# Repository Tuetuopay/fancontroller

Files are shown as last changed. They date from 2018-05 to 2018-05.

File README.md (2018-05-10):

# FanController

*Creative naming?* What is this?

Rheobus project rooted from a simple problem: all my PC fans are DC only (the
three wire kind), but my motherboard only supports PWM*. And why buy a
commercial one? Let's make my own!

*Even if it does, shhhh! This is a good excuse for a project!

## Hardware

Simple PCB designed with Eagle. It can control up to 8 fans, with an STM32F103
as a brain. On the extra side, there is an LED for each channel, because
blinkenlights are cool. For communications, this is scarce: a USB port and
UART or I2C header.

The PCB is mostly finished, some refinements may be needed. It is well under
10cm x 10cm to be ordered on the cheap from the likes of DirtyPCB or JLCPCB.

All parts are SMD (except for headers and the one quartz), but do not go smaller
than 0603 resistors, easily solderable by hand. They can all be easily sourced
from Ebay.

## Software

This is not written yet. I plan on doing it with ChibiOS, just for kicks. It is
well supported on the STM32 platform, easy to use (once you accepted the fact
that documentation is almost nonexistent).

# Licence

```
THE BEER-WARE LICENSE (Revision 42):
tuetuopay at me dot com wrote this file. As long as you retain this notice you
can do whatever you want with this stuff. If we meet some day, and you think
this stuff is worth it, you can buy me a beer in return. Tuetuopay.
```

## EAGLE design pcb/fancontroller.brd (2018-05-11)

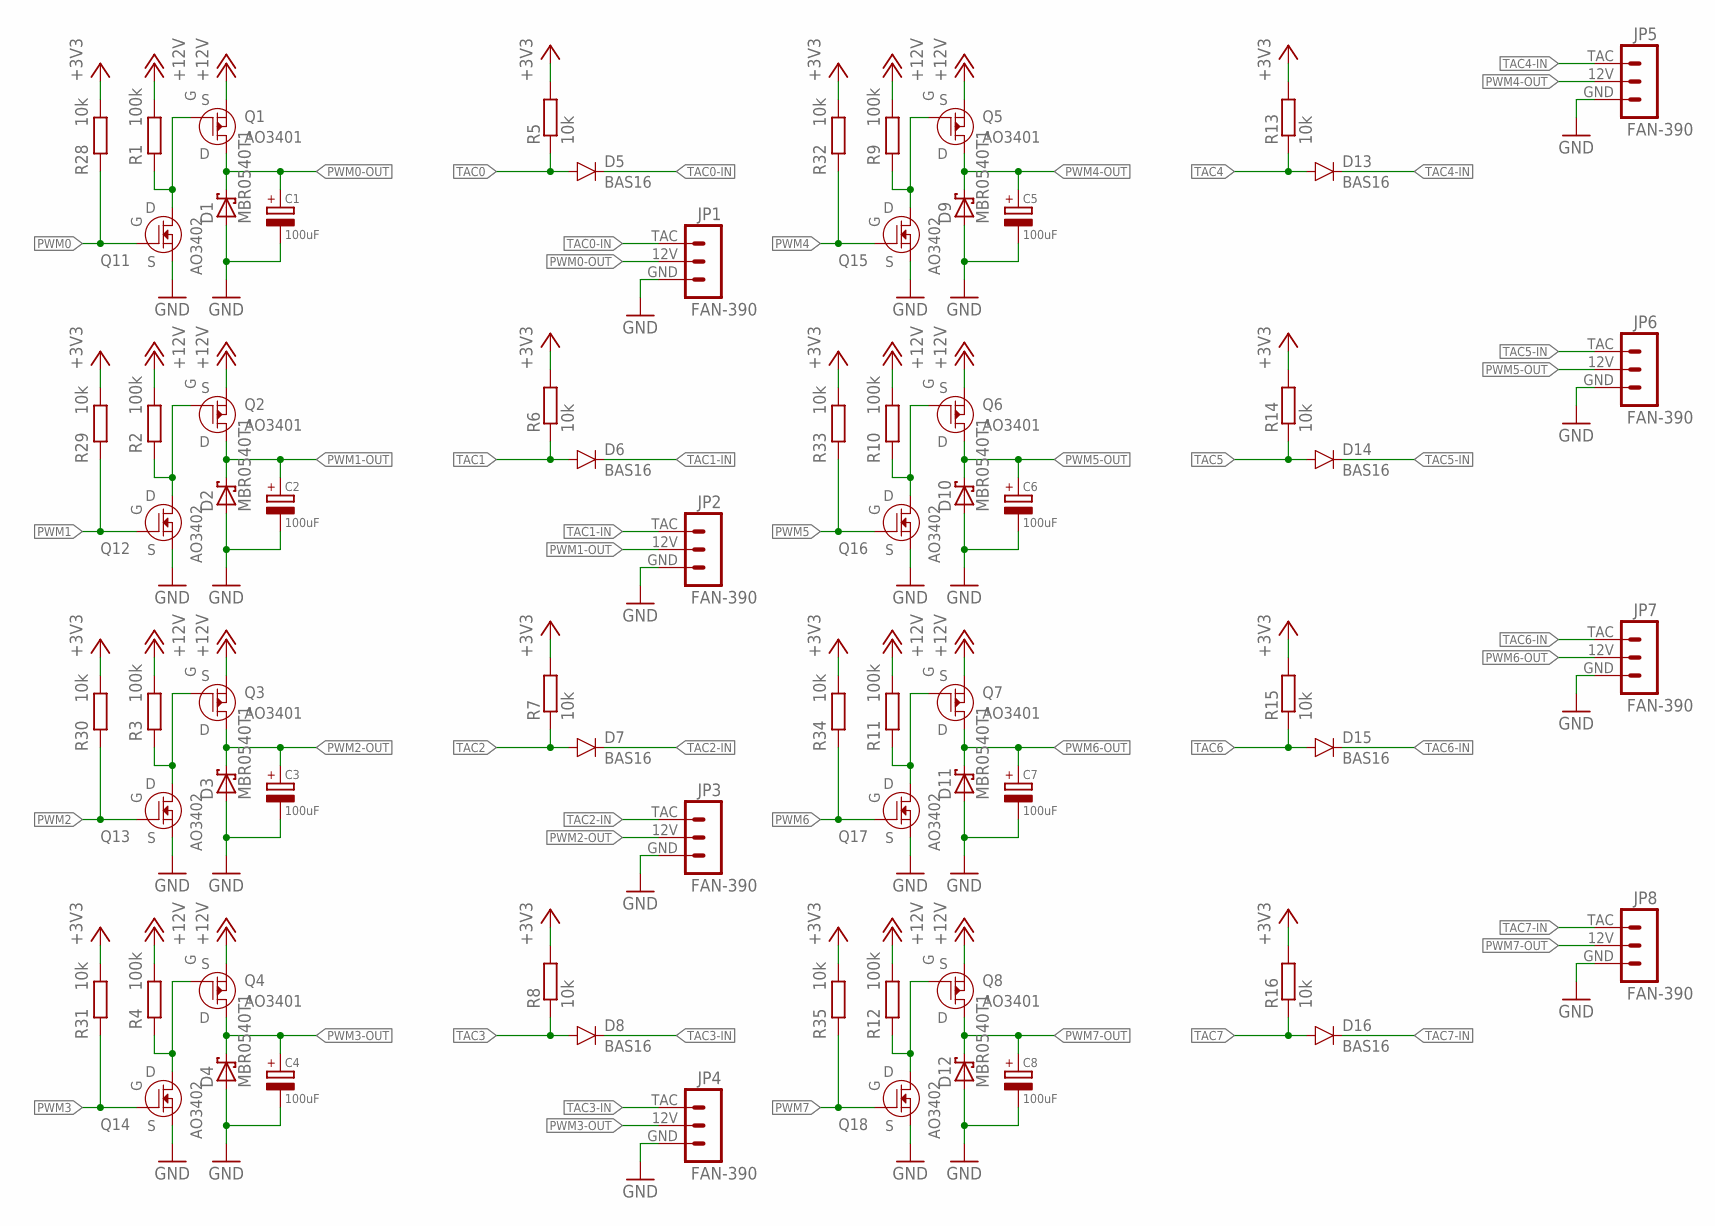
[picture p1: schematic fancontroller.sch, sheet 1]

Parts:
C1, C2, C3, C4, C5, C6, C7, C8: 100uF; CAP-D6.3
D1, D2, D3, D4, D9, D10, D11, D12: MBR0540T1; SOD123
D5, D6, D7, D8, D13, D14, D15, D16: BAS16; SOT23-3
JP1, JP2, JP3, JP4, JP5, JP6, JP7, JP8: FAN-390; FAN-3PIN/90
Q1, Q2, Q3, Q4, Q5, Q6, Q7, Q8: AO3401; SOT23-3
Q11, Q12, Q13, Q14, Q15, Q16, Q17, Q18: AO3402; SOT23-3
R1, R2, R3, R4, R9, R10, R11, R12: 100k; R0603
R5, R6, R7, R8, R13, R14, R15, R16, R28, R29, R30, R31, R32, R33, R34, R35: 10k; R0603

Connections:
+3V3: R5.2, R6.2, R7.2, R8.2, R13.2, R14.2, R15.2, R16.2, R28.2, R29.2, R30.2, R31.2, R32.2, R33.2, R34.2, R35.2; also elsewhere on the board
+12V: Q1.2 (S), Q2.2 (S), Q3.2 (S), Q4.2 (S), Q5.2 (S), Q6.2 (S), Q7.2 (S), Q8.2 (S), R1.2, R2.2, R3.2, R4.2, R9.2, R10.2, R11.2, R12.2; also elsewhere on the board
GND: C1.N (NEG), C2.N (NEG), C3.N (NEG), C4.N (NEG), C5.N (NEG), C6.N (NEG), C7.N (NEG), C8.N (NEG), D1.A, D2.A, D3.A, D4.A, D9.A, D10.A, D11.A, D12.A, JP1.GND (1), JP2.GND (1), JP3.GND (1), JP4.GND (1), JP5.GND (1), JP6.GND (1), JP7.GND (1), JP8.GND (1), Q11.2 (S), Q12.2 (S), Q13.2 (S), Q14.2 (S), Q15.2 (S), Q16.2 (S), Q17.2 (S), Q18.2 (S); also elsewhere on the board
PWM0: Q11.1 (G), R28.1; also elsewhere on the board
PWM0-1: Q1.1 (G), Q11.3 (D), R1.1
PWM0-OUT: C1.P (POS), D1.C, JP1.12V (2), Q1.3 (D)
PWM1: Q12.1 (G), R29.1; also elsewhere on the board
PWM1-1: Q2.1 (G), Q12.3 (D), R2.1
PWM1-OUT: C2.P (POS), D2.C, JP2.12V (2), Q2.3 (D)
PWM2: Q13.1 (G), R30.1; also elsewhere on the board
PWM2-1: Q3.1 (G), Q13.3 (D), R3.1
PWM2-OUT: C3.P (POS), D3.C, JP3.12V (2), Q3.3 (D)
PWM3: Q14.1 (G), R31.1; also elsewhere on the board
PWM3-1: Q4.1 (G), Q14.3 (D), R4.1
PWM3-OUT: C4.P (POS), D4.C, JP4.12V (2), Q4.3 (D)
PWM4: Q15.1 (G), R32.1; also elsewhere on the board
PWM4-1: Q5.1 (G), Q15.3 (D), R9.1
PWM4-OUT: C5.P (POS), D9.C, JP5.12V (2), Q5.3 (D)
PWM5: Q16.1 (G), R33.1; also elsewhere on the board
PWM5-1: Q6.1 (G), Q16.3 (D), R10.1
PWM5-OUT: C6.P (POS), D10.C, JP6.12V (2), Q6.3 (D)
PWM6: Q17.1 (G), R34.1; also elsewhere on the board
PWM6-1: Q7.1 (G), Q17.3 (D), R11.1
PWM6-OUT: C7.P (POS), D11.C, JP7.12V (2), Q7.3 (D)
PWM7: Q18.1 (G), R35.1; also elsewhere on the board
PWM7-1: Q8.1 (G), Q18.3 (D), R12.1
PWM7-OUT: C8.P (POS), D12.C, JP8.12V (2), Q8.3 (D)
TAC0: D5.1 (A), R5.1; also elsewhere on the board
TAC0-IN: D5.3 (C), JP1.TAC (3)
TAC1: D6.1 (A), R6.1; also elsewhere on the board
TAC1-IN: D6.3 (C), JP2.TAC (3)
TAC2: D7.1 (A), R7.1; also elsewhere on the board
TAC2-IN: D7.3 (C), JP3.TAC (3)
TAC3: D8.1 (A), R8.1; also elsewhere on the board
TAC3-IN: D8.3 (C), JP4.TAC (3)
TAC4: D13.1 (A), R13.1; also elsewhere on the board
TAC4-IN: D13.3 (C), JP5.TAC (3)
TAC5: D14.1 (A), R14.1; also elsewhere on the board
TAC5-IN: D14.3 (C), JP6.TAC (3)
TAC6: D15.1 (A), R15.1; also elsewhere on the board
TAC6-IN: D15.3 (C), JP7.TAC (3)
TAC7: D16.1 (A), R16.1; also elsewhere on the board
TAC7-IN: D16.3 (C), JP8.TAC (3)

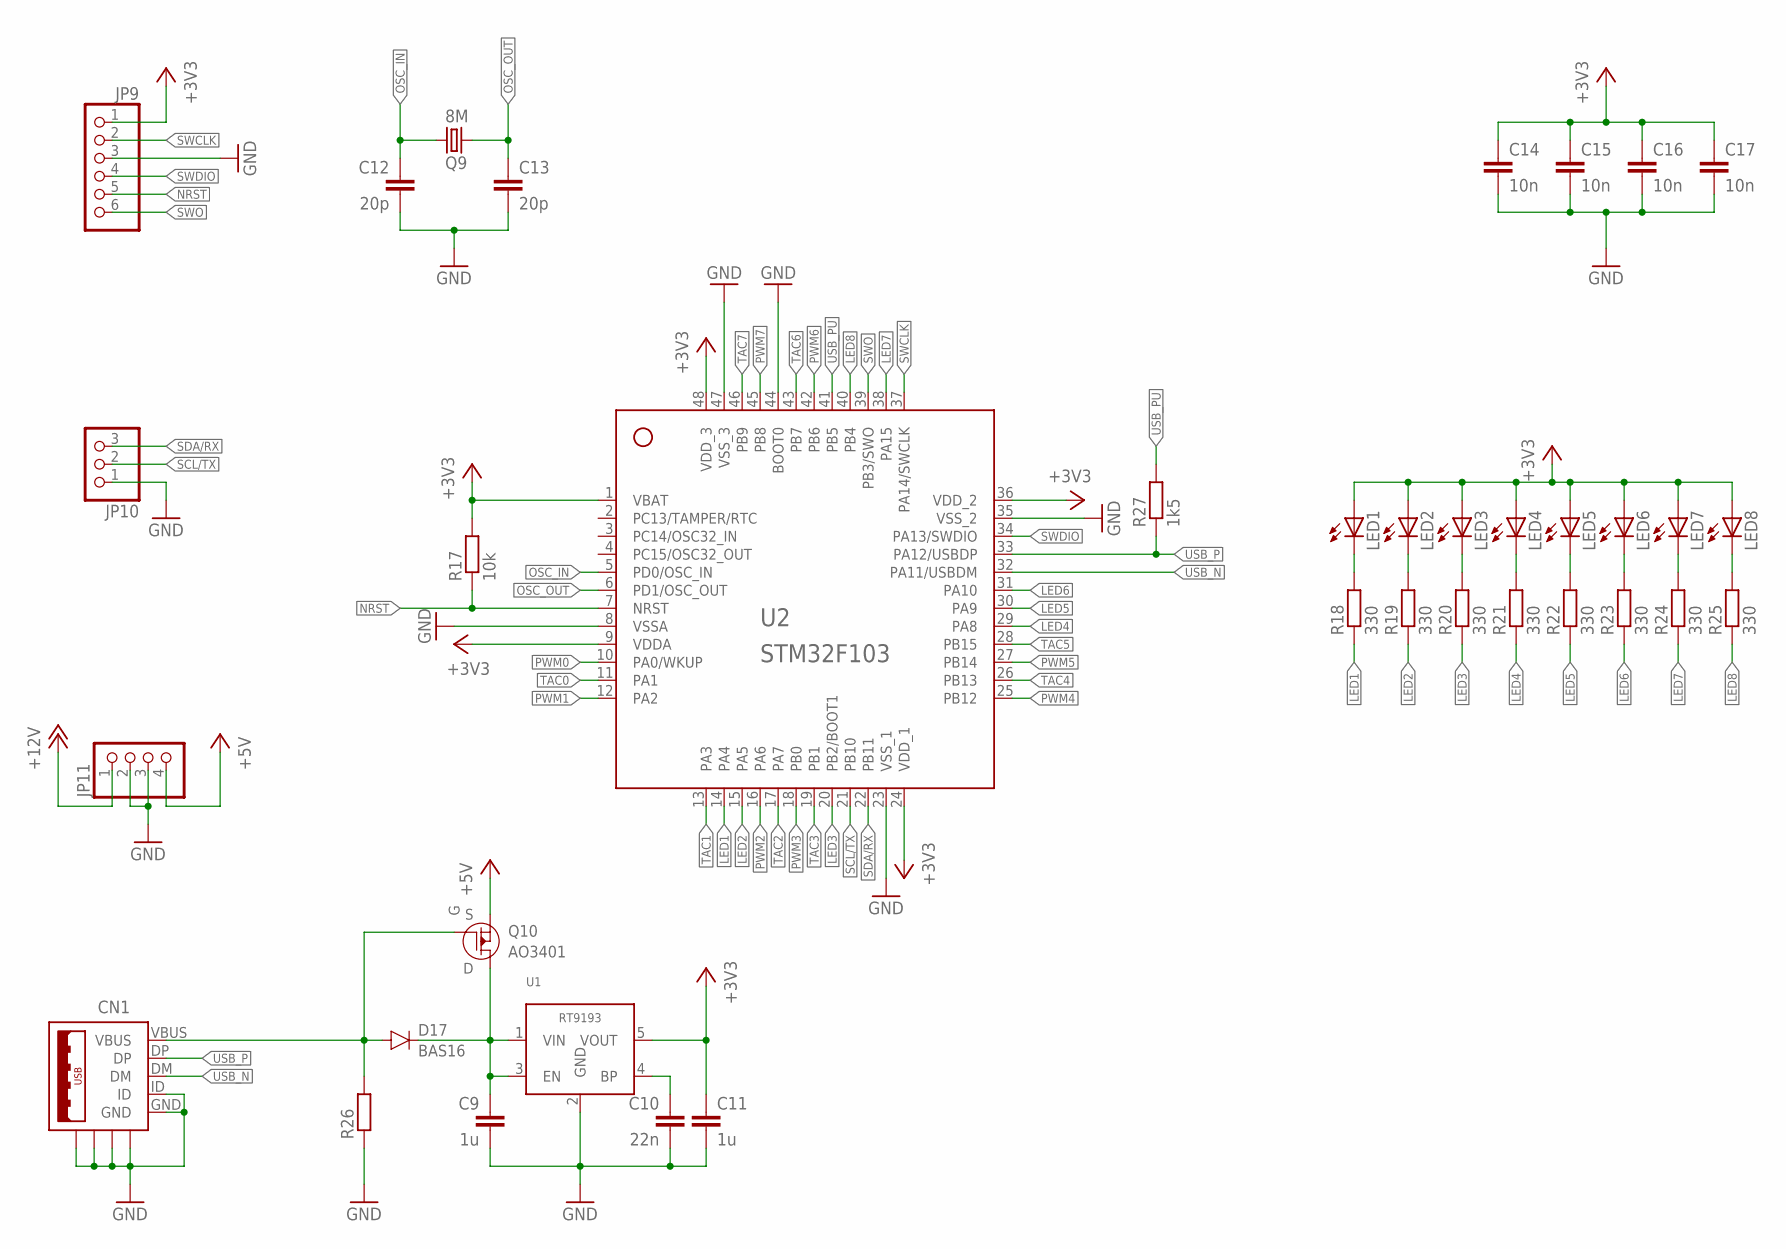
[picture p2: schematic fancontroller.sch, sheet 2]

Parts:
C9, C11: 1u; 0603
C10: 22n; 0603
C12, C13: 20p; 0603
C14, C15, C16, C17: 10n; 0603
CN1: USB-MICROB-2TABS; USB-MICROB-2
D17: BAS16; SOT23-3
JP9: PINHD-1X6; 1X06
JP10: PINHD-1X3/90; 1X03/90
JP11: PINHD-1X4/90; 1X04/90
LED1, LED2, LED3, LED4, LED5, LED6, LED7, LED8: LEDSML0805; SML0805
Q9: 8M; HC49/S
Q10: AO3401; SOT23-3
R17: 10k; R0603
R18, R19, R20, R21, R22, R23, R24, R25: 330; R0603
R26: RR0603; R0603
R27: 1k5; R0603
U1: RT9193; SOT23-5
U2: STM32F103-48LQFP; LQFP-48

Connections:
+3V3: C11.1, C14.1, C15.1, C16.1, C17.1, JP9.1, LED1.A, LED2.A, LED3.A, LED4.A, LED5.A, LED6.A, LED7.A, LED8.A, R17.2, U1.5 (VOUT), U2.1 (VBAT), U2.9 (VDDA), U2.24 (VDD_1), U2.36 (VDD_2), U2.48 (VDD_3); also elsewhere on the board
+5V: JP11.4, Q10.2 (S)
+12V: JP11.1; also elsewhere on the board
GND: C9.2, C10.2, C11.2, C12.2, C13.2, C14.2, C15.2, C16.2, C17.2, CN1.GND, CN1.GND@1 (GND), CN1.GND@2 (GND), CN1.GND@3 (GND), CN1.GND@4 (GND), CN1.ID, JP9.3, JP10.1, JP11.2, JP11.3, R26.1, U1.2 (GND), U2.8 (VSSA), U2.23 (VSS_1), U2.35 (VSS_2), U2.44 (BOOT0), U2.47 (VSS_3); also elsewhere on the board
LED1: R18.1, U2.14 (PA4)
LED2: R19.1, U2.15 (PA5)
LED3: R20.1, U2.20 (PB2/BOOT1)
LED4: R21.1, U2.29 (PA8)
LED5: R22.1, U2.30 (PA9)
LED6: R23.1, U2.31 (PA10)
LED7: R24.1, U2.38 (PA15)
LED8: R25.1, U2.40 (PB4)
unnamed: LED3.C, R20.2
unnamed: LED2.C, R19.2
unnamed: LED1.C, R18.2
unnamed: LED4.C, R21.2
unnamed: LED7.C, R24.2
unnamed: LED8.C, R25.2
unnamed: LED5.C, R22.2
unnamed: LED6.C, R23.2
unnamed: C10.1, U1.4 (BP)
NRST: JP9.5, R17.1, U2.7 (NRST)
OSC_IN: C12.1, Q9.1, U2.5 (PD0/OSC_IN)
OSC_OUT: C13.1, Q9.2, U2.6 (PD1/OSC_OUT)
PWM0: U2.10 (PA0/WKUP); also elsewhere on the board
PWM1: U2.12 (PA2); also elsewhere on the board
PWM2: U2.16 (PA6); also elsewhere on the board
PWM3: U2.18 (PB0); also elsewhere on the board
PWM4: U2.25 (PB12); also elsewhere on the board
PWM5: U2.27 (PB14); also elsewhere on the board
PWM6: U2.42 (PB6); also elsewhere on the board
PWM7: U2.45 (PB8); also elsewhere on the board
SCL/TX: JP10.2, U2.21 (PB10)
SDA/RX: JP10.3, U2.22 (PB11)
SWCLK: JP9.2, U2.37 (PA14/SWCLK)
SWDIO: JP9.4, U2.34 (PA13/SWDIO)
SWO: JP9.6, U2.39 (PB3/SWO)
TAC0: U2.11 (PA1); also elsewhere on the board
TAC1: U2.13 (PA3); also elsewhere on the board
TAC2: U2.17 (PA7); also elsewhere on the board
TAC3: U2.19 (PB1); also elsewhere on the board
TAC4: U2.26 (PB13); also elsewhere on the board
TAC5: U2.28 (PB15); also elsewhere on the board
TAC6: U2.43 (PB7); also elsewhere on the board
TAC7: U2.46 (PB9); also elsewhere on the board
USB_N: CN1.DM, U2.32 (PA11/USBDM)
USB_P: CN1.DP, R27.1, U2.33 (PA12/USBDP)
USB_PU: R27.2, U2.41 (PB5)
VBUS: CN1.VBUS, D17.1 (A), Q10.1 (G), R26.2
VIN: C9.1, D17.3 (C), Q10.3 (D), U1.1 (VIN), U1.3 (EN)

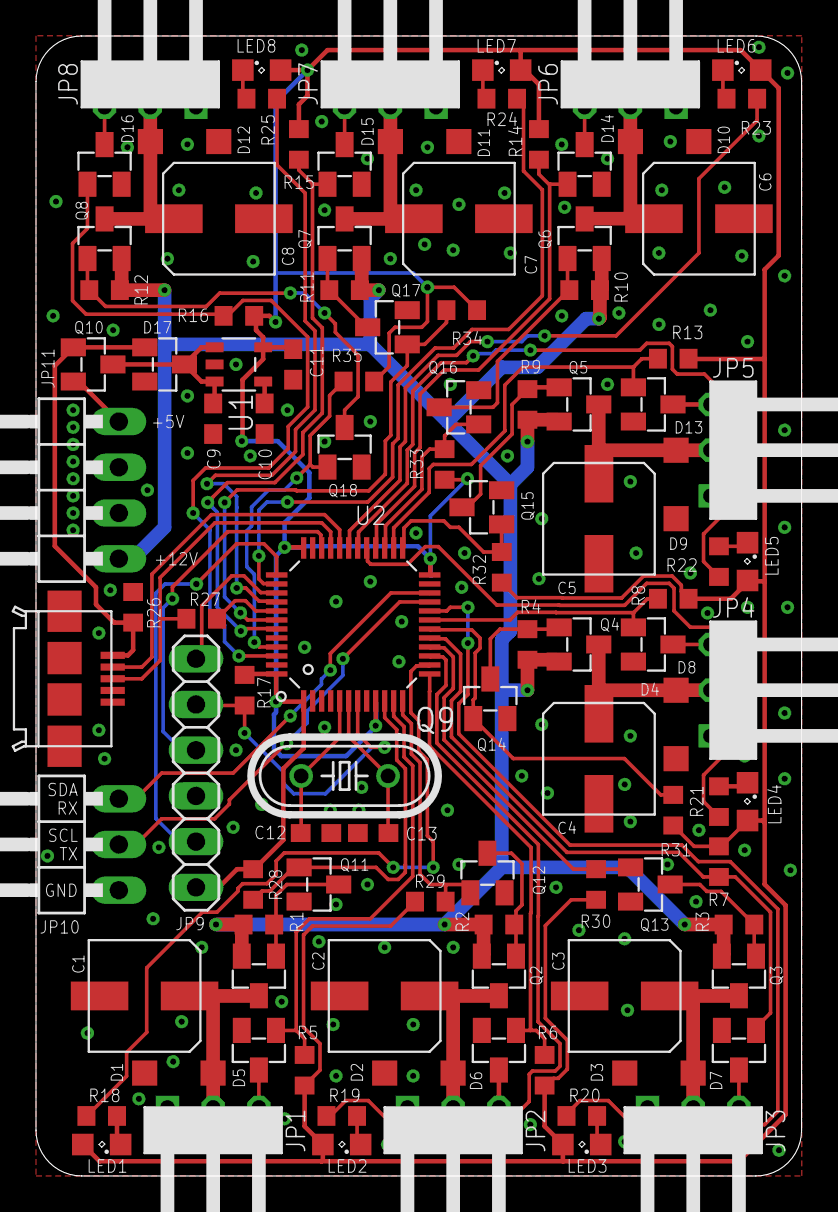
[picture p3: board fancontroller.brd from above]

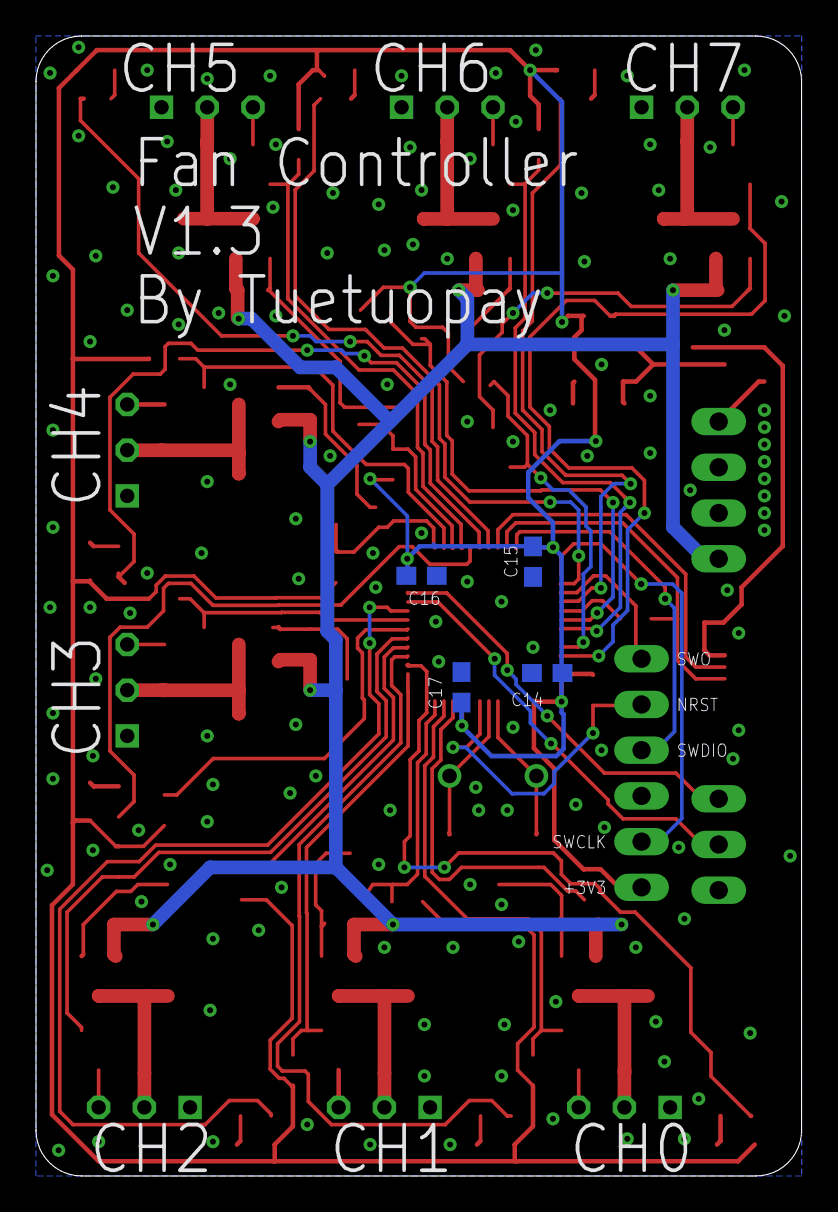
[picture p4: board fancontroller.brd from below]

Board: 2 copper layers, 42.5 x 63.3 mm, 109 parts (4 on the bottom side), 74 nets.

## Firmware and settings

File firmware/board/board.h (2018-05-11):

/* THE BEER-WARE LICENSE (Revision 42):
 * tuetuopay at me dot com wrote this file. As long as you retain this notice
 * you can do whatever you want with this stuff. If we meet some day, and you
 * think this stuff is worth it, you can buy me a beer in return. Tuetuopay.
 */

#ifndef _BOARD_BOARD_H_
#define _BOARD_BOARD_H_

/*
 * Setup for the FanController board.
 */

/*
 * Board identifier.
 */
#define BOARD_FAN_CONTROLLER
#define BOARD_NAME              "FanController"

/*
 * Board frequencies.
 */
#define STM32_LSECLK            32768
#define STM32_HSECLK            8000000

/*
 * MCU type, supported types are defined in ./os/hal/platforms/hal_lld.h.
 */
#define STM32F103xB

/*
 * IO pins assignments
 */

#define GPIOA_PWM0              0
#define GPIOA_TAC0              1
#define GPIOA_PWM1              2
#define GPIOA_TAC1              3
#define GPIOA_LED1              4
#define GPIOA_LED2              5
#define GPIOA_PWM2              6
#define GPIOA_TAC2              7
#define GPIOA_LED4              8
#define GPIOA_LED5              9
#define GPIOA_LED6              10
#define GPIOA_USB_DM            11
#define GPIOA_USB_DP            12
#define GPIOA_LED7              15

#define GPIOB_PWM3              0
#define GPIOB_TAC3              1
#define GPIOB_LED3              2
#define GPIOB_LED8              4
#define GPIOB_USB_PU            5
#define GPIOB_PWM6              6
#define GPIOB_TAC6              7
#define GPIOB_PWM7              8
#define GPIOB_TAC7              9
#define GPIOB_SCL_TXD           10
#define GPIOB_SDA_RXD           11
#define GPIOB_PWM4              12
#define GPIOB_TAC4              13
#define GPIOB_PWM5              14
#define GPIOB_TAC5              15

// Port C is not used

#define GPIOD_OSC_IN            0
#define GPIOD_OSC_OUT           1

/*
 * IO lines assignments.
 */
#define LINE_PWM0              PAL_LINE(GPIOA, 0)
#define LINE_TAC0              PAL_LINE(GPIOA, 1)
#define LINE_PWM1              PAL_LINE(GPIOA, 2)
#define LINE_TAC1              PAL_LINE(GPIOA, 3)
#define LINE_LED1              PAL_LINE(GPIOA, 4)
#define LINE_LED2              PAL_LINE(GPIOA, 5)
#define LINE_PWM2              PAL_LINE(GPIOA, 6)
#define LINE_TAC2              PAL_LINE(GPIOA, 7)
#define LINE_LED4              PAL_LINE(GPIOA, 8)
#define LINE_LED5              PAL_LINE(GPIOA, 9)
#define LINE_LED6              PAL_LINE(GPIOA, 10)
#define LINE_USB_DM            PAL_LINE(GPIOA, 11)
#define LINE_USB_DP            PAL_LINE(GPIOA, 12)
#define LINE_LED7              PAL_LINE(GPIOA, 15)

#define LINE_PWM3              PAL_LINE(GPIOB, 0)
#define LINE_TAC3              PAL_LINE(GPIOB, 1)
#define LINE_LED3              PAL_LINE(GPIOB, 2)
#define LINE_LED8              PAL_LINE(GPIOB, 4)
#define LINE_USB_PU            PAL_LINE(GPIOB, 5)
#define LINE_PWM6              PAL_LINE(GPIOB, 6)
#define LINE_TAC6              PAL_LINE(GPIOB, 7)
#define LINE_PWM7              PAL_LINE(GPIOB, 8)
#define LINE_TAC7              PAL_LINE(GPIOB, 9)
#define LINE_SCL_TXD           PAL_LINE(GPIOB, 10)
#define LINE_SDA_RXD           PAL_LINE(GPIOB, 11)
#define LINE_PWM4              PAL_LINE(GPIOB, 12)
#define LINE_TAC4              PAL_LINE(GPIOB, 13)
#define LINE_PWM5              PAL_LINE(GPIOB, 14)
#define LINE_TAC5              PAL_LINE(GPIOB, 15)

// Port C is not used

#define LINE_OSC_IN            PAL_LINE(GPIOD, 0)
#define LINE_OSC_OUT           PAL_LINE(GPIOD, 1)

/*
 * I/O ports initial setup, this configuration is established soon after reset
 * in the initialization code.
 *
 * The digits have the following meaning:
 *   0 - Analog input.
 *   1 - Push Pull output 10MHz.
 *   2 - Push Pull output 2MHz.
 *   3 - Push Pull output 50MHz.
 *   4 - Digital input.
 *   5 - Open Drain output 10MHz.
 *   6 - Open Drain output 2MHz.
 *   7 - Open Drain output 50MHz.
 *   8 - Digital input with PullUp or PullDown resistor depending on ODR.
 *   9 - Alternate Push Pull output 10MHz.
 *   A - Alternate Push Pull output 2MHz.
 *   B - Alternate Push Pull output 50MHz.
 *   C - Reserved.
 *   D - Alternate Open Drain output 10MHz.
 *   E - Alternate Open Drain output 2MHz.
 *   F - Alternate Open Drain output 50MHz.
 * Please refer to the STM32 Reference Manual for details.
 */

/*
 * Port A setup.
 * Everything input with pull-up.
 */
#define VAL_GPIOACRL            0x00000000      /*  PA7...PA0 */
#define VAL_GPIOACRH            0x00000000      /* PA15...PA8 */
#define VAL_GPIOAODR            0xFFFFFFFF

/*
 * Port B setup.
 * Everything input floating
 */
#define VAL_GPIOBCRL            0x00000000      /*  PB7...PB0 */
#define VAL_GPIOBCRH            0x00000000      /* PB15...PB8 */
#define VAL_GPIOBODR            0xFFFFFFFF

/*
 * Port C setup.
 * Everything input floating:
 */
#define VAL_GPIOCCRL            0x00000000      /*  PC7...PC0 */
#define VAL_GPIOCCRH            0x00000000      /* PC15...PC8 */
#define VAL_GPIOCODR            0xFFFFFFFF
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

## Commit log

2018-05-10 pcb: Add rev. 1.3
    [fancontroller.brd, fancontroller.sch]
2018-05-11 fw: Add USB pullup for next board revision
2018-05-11 pcb: Connect USB pull-up resistor to GPIO
    [fancontroller.brd, fancontroller.sch]
2018-05-11 pcb: Move header silkscreen to top
    [fancontroller.brd]
2018-05-11 pcb: Move misc designators for better readability
    [fancontroller.brd]
2018-05-12 fw: Add LED driver
2018-05-12 fw: Add led shell command
2018-05-12 fw: Add PWM driver for the fans
